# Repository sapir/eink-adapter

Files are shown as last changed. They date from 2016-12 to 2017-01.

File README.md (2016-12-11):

# E-Ink adapter board and driver code

See https://hackaday.io/project/7443-e-ink-display-adapter.

### Previous work and licensing

This is heavily based on previous work:
 * PetteriAimonen [explanations and PCB](http://essentialscrap.com/eink/index.html) (unknown license) and [driver code](https://github.com/PetteriAimonen/ED060SC4_driver) (public domain license)
 * Sprite_tm [explanations and PCB](http://spritesmods.com/?art=einkdisplay) (CC-BY-SA license) and [driver code](http://git.spritesserver.nl/espeink.git/) [(here's a github fork)](https://github.com/take-i/espeink) (beer-ware license)
 * zephray [NekoCal project](https://github.com/nbzwt/NekoCal), in particular the driver code (MIT license)

Additionally, the driver code uses the [esp-open-rtos ESP8266 SDK](https://github.com/Superhouse/esp-open-rtos.git) (various licenses).

As far as I'm concerned, I'd license this repository under the MIT license, but
the PCB may be under CC-BY-SA, and there may be other restrictions if you use
the esp-open-rtos SDK.

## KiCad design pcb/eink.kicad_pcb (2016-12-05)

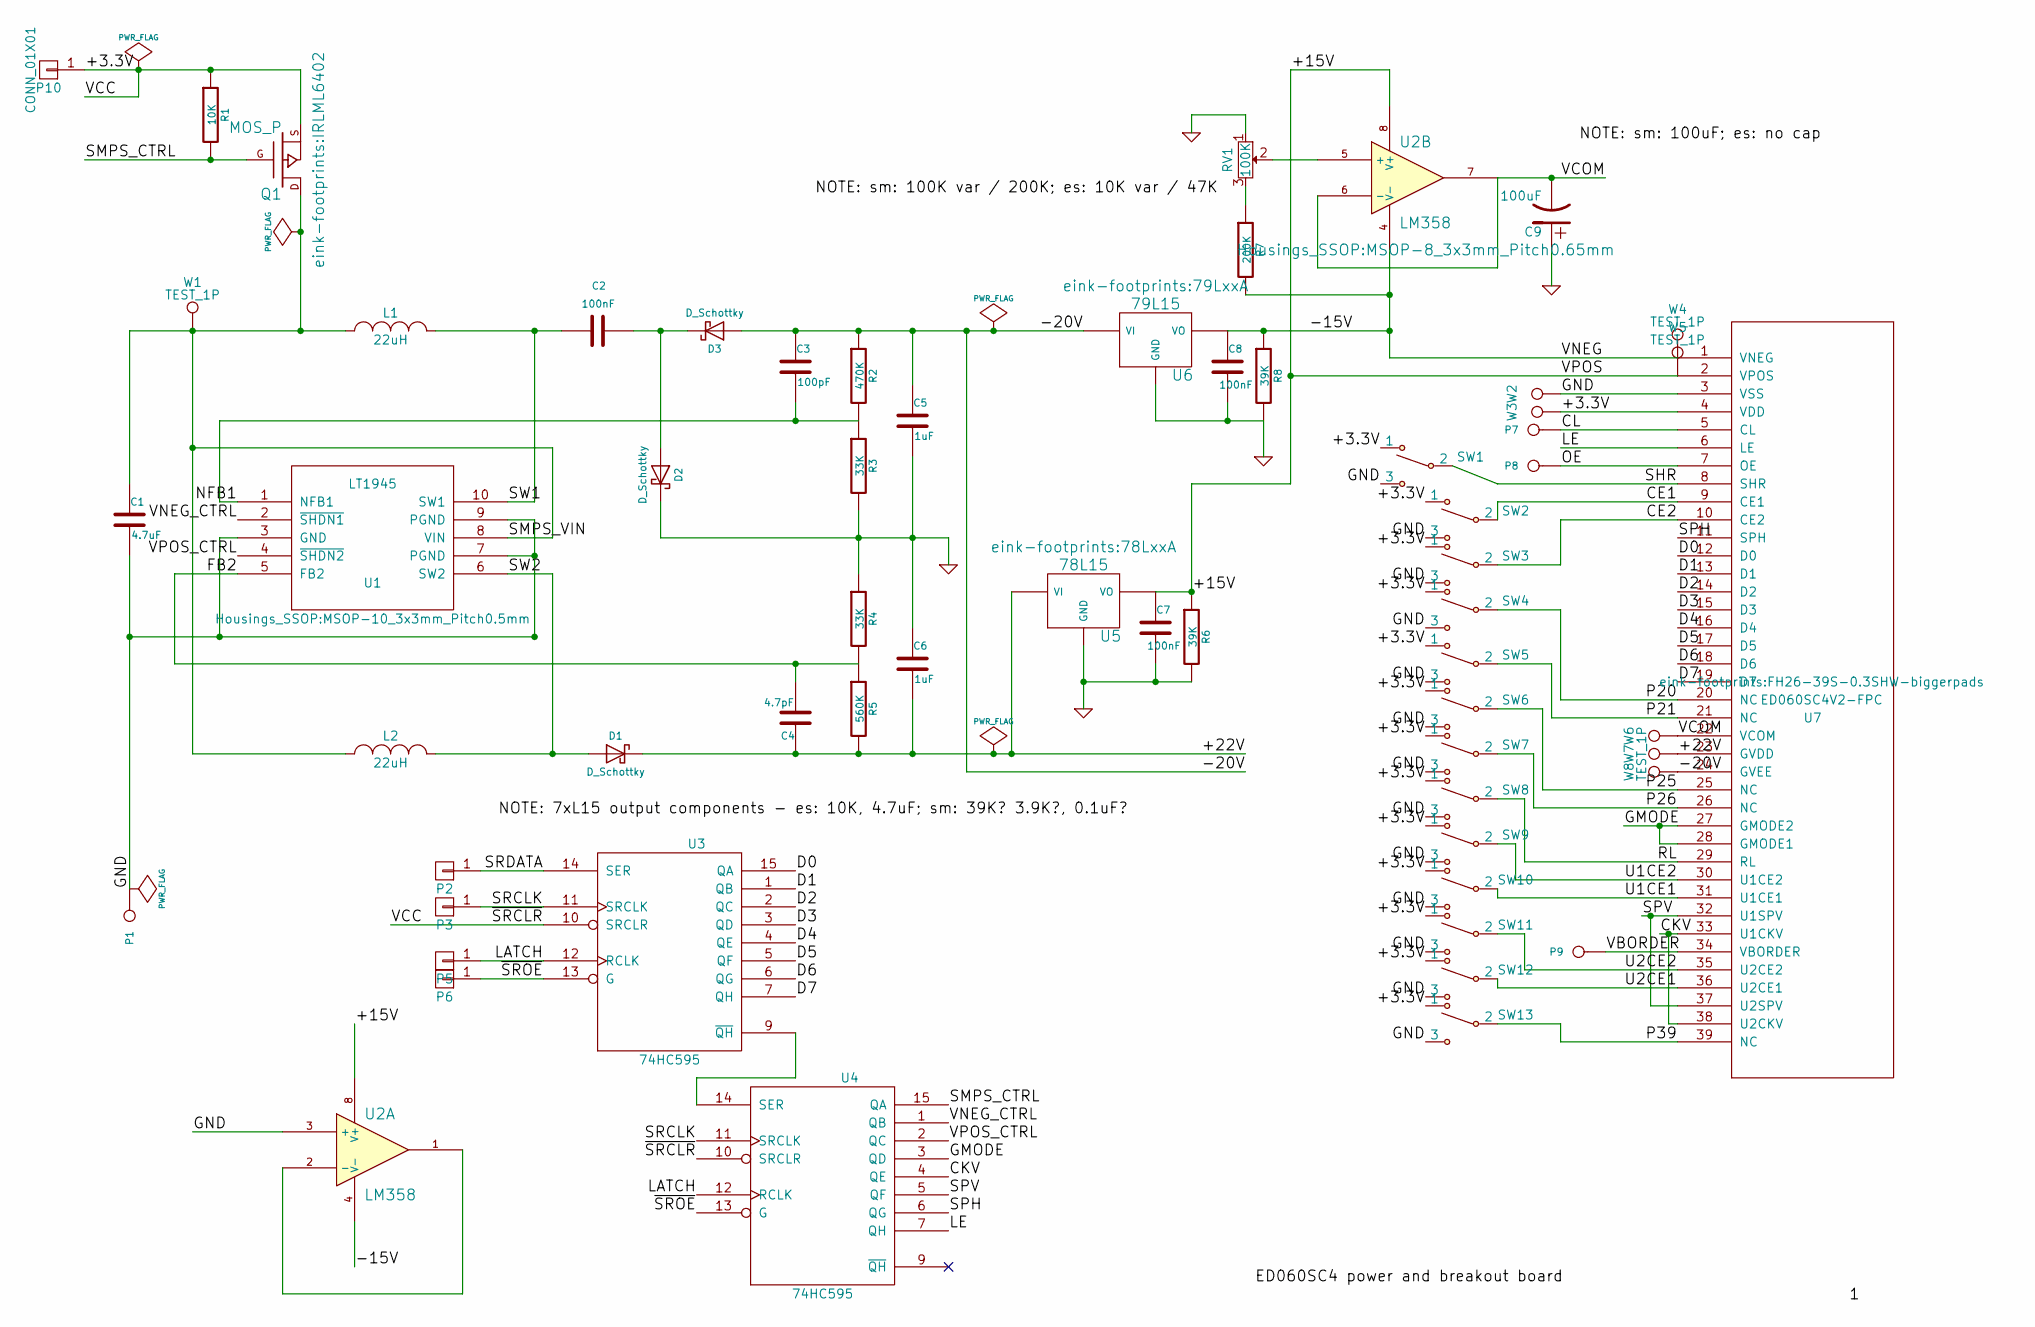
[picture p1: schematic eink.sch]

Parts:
C1: 4.7uF; C_0805_HandSoldering
C2, C7, C8: 100nF; C_0805_HandSoldering
C3: 100pF; C_0805_HandSoldering
C4: 4.7pF; C_0805_HandSoldering
C5, C6: 1uF; C_0805_HandSoldering
C9: 100uF; C_Radial_D5_L6_P2.5
D1, D2, D3: D_Schottky; SMB-SMC_Universal_Handsoldering
L1, L2: 22uH; SELF-WE-TPC_M
P1, P7, P8, P9: CONN_1; Pin_Header_Straight_1x01
P2, P3, P5, P6, P10: CONN_01X01; Pin_Header_Straight_1x01
Q1: MOS_P; IRLML6402
R1: 10K; R_0805_HandSoldering
R2: 470K; R_0805_HandSoldering
R3, R4: 33K; R_0805_HandSoldering
R5: 560K; R_0805_HandSoldering
R6, R8: 39K; R_0805_HandSoldering
R7: 200K; R_0805_HandSoldering
RV1: 100K; Bourns_3314G-1-biggerpads
SW1, SW2, SW3, SW4, SW5, SW6, SW7, SW8, SW9, SW10, SW11, SW12, SW13: SW_SPDT_Small; Pin_Header_Straight_1x03
U1: LT1945; MSOP-10_3x3mm_Pitch0.5mm
U2: LM358; MSOP-8_3x3mm_Pitch0.65mm
U3, U4: 74HC595; DIP-16_W7.62mm_LongPads
U5: 78L15; 78LxxA
U6: 79L15; 79LxxA
U7: ED060SC4V2-FPC; FH26-39S-0.3SHW-biggerpads
W1, W2, W3, W4, W5, W6, W7, W8: TEST_1P; Measurement_Point_Round-TH_Big

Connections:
/+15V: C7.1, R6.1, U2.8 (V+), U5.VO, U7.2 (VPOS), W5.1
/+22V: C4.1, C6.2, D1.1 (K), R5.2, U5.VI, U7.23 (GVDD), W7.1
/-15V: C8.1, R7.2, R8.1, U2.4 (V-), U6.VO, U7.1 (VNEG), W4.1
/-20V: C3.1, C5.1, D3.2 (A), R2.1, U6.VI, U7.24 (GVEE), W8.1
/CE1: SW2.2, U7.9 (CE1)
/CE2: SW3.2, U7.10 (CE2)
/CKV: U4.4 (QE), U7.33 (U1CKV), U7.38 (U2CKV)
/CL: P7.1, U7.5 (CL)
/D0: U3.15 (QA), U7.12 (D0)
/D1: U3.1 (QB), U7.13 (D1)
/D2: U3.2 (QC), U7.14 (D2)
/D3: U3.3 (QD), U7.15 (D3)
/D4: U3.4 (QE), U7.16 (D4)
/D5: U3.5 (QF), U7.17 (D5)
/D6: U3.6 (QG), U7.18 (D6)
/D7: U3.7 (QH), U7.19 (D7)
/FB2: C4.2, R4.2, R5.1, U1.5 (FB2)
/GMODE: U4.3 (QD), U7.27 (GMODE2), U7.28 (GMODE1)
/LATCH: P5.1, U3.12 (RCLK), U4.12 (RCLK)
/LE: U4.7 (QH), U7.6 (LE)
/NFB1: C3.2, R2.2, R3.1, U1.1 (NFB1)
/OE: P8.1, U7.7 (OE)
/P20: SW4.2, U7.20 (NC)
/P21: SW5.2, U7.21 (NC)
/P25: SW6.2, U7.25 (NC)
/P26: SW7.2, U7.26 (NC)
/P39: SW13.2, U7.39 (NC)
/RL: SW8.2, U7.29 (RL)
/SHR: SW1.2, U7.8 (SHR)
/SMPS_CTRL: Q1.G, R1.2, U4.15 (QA)
/SMPS_VIN: C1.1, L1.1, L2.1, Q1.D, U1.8 (VIN), W1.1
/SPH: U4.6 (QG), U7.11 (SPH)
/SPV: U4.5 (QF), U7.32 (U1SPV), U7.37 (U2SPV)
/SRCLK: P3.1, U3.11 (SRCLK), U4.11 (SRCLK)
/SRDATA: P2.1, U3.14 (SER)
/SW1: C2.1, L1.2, U1.10 (SW1)
/SW2: D1.2 (A), L2.2, U1.6 (SW2)
/U1CE1: SW10.2, U7.31 (U1CE1)
/U1CE2: SW9.2, U7.30 (U1CE2)
/U2CE1: SW12.2, U7.36 (U2CE1)
/U2CE2: SW11.2, U7.35 (U2CE2)
/VBORDER: P9.1, U7.34 (VBORDER)
/VCOM: C9.2, U2.6 (-), U2.7, U7.22 (VCOM), W6.1
/VNEG_CTRL: U1.2 (~SHDN1~), U4.1 (QB)
/VPOS_CTRL: U1.4 (~SHDN2~), U4.2 (QC)
/~SROE~: P6.1, U3.13 (G), U4.13 (G)
GND: C1.2, C5.2, C6.1, C7.2, C8.2, C9.1, D2.1 (K), P1.1, R3.2, R4.1, R6.2, R8.2, RV1.1, SW1.3, SW2.3, SW3.3, SW4.3, SW5.3, SW6.3, SW7.3, SW8.3, SW9.3, SW10.3, SW11.3, SW12.3, SW13.3, U1.3 (GND), U1.7 (PGND), U1.9 (PGND), U2.3 (+), U3.8 (GND), U4.8 (GND), U5.GND, U6.GND, U7.3 (VSS), W2.1
unnamed: C2.2, D2.2 (A), D3.1 (K)
unnamed: R7.1, RV1.3
unnamed: RV1.2, U2.5 (+)
unnamed: U2.1, U2.2 (-)
unnamed: U3.9 (~QH), U4.14 (SER)
VCC: P10.1, Q1.S, R1.1, SW1.1, SW2.1, SW3.1, SW4.1, SW5.1, SW6.1, SW7.1, SW8.1, SW9.1, SW10.1, SW11.1, SW12.1, SW13.1, U3.10 (SRCLR), U3.16 (VCC), U4.10 (SRCLR), U4.16 (VCC), U7.4 (VDD), W3.1

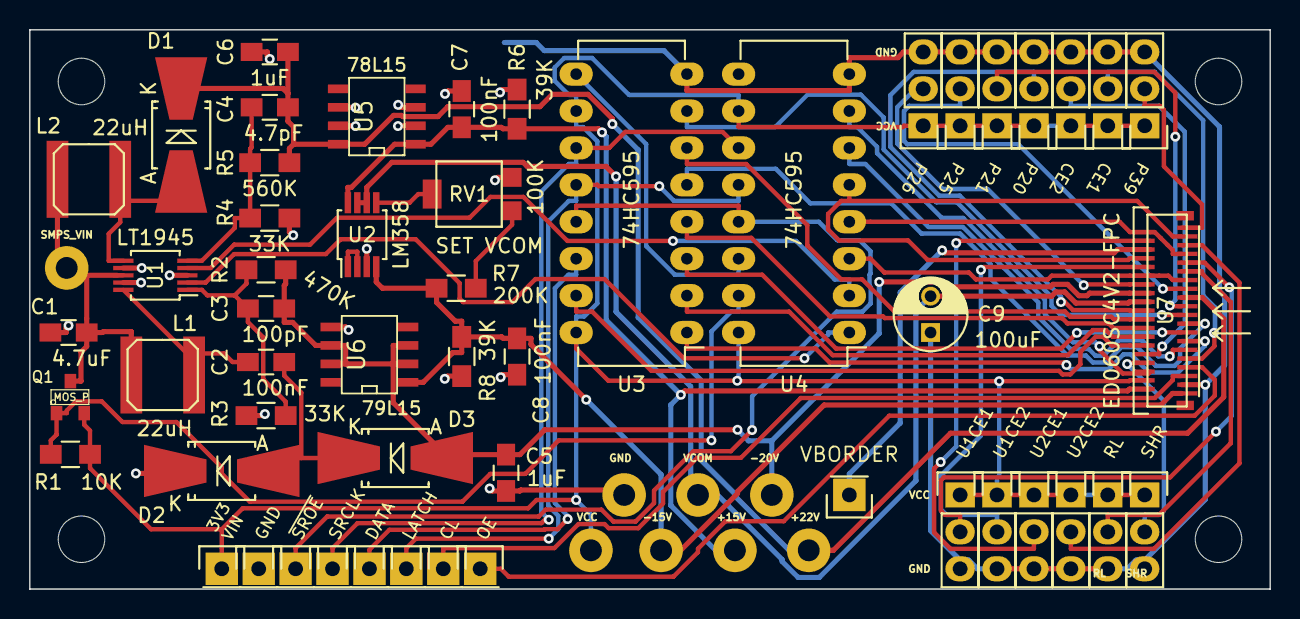
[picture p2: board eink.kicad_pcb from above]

Board: 2 copper layers, 85.3 x 38.5 mm, 65 parts (0 on the bottom side), 53 nets.

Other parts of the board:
MNT1, MNT2, MNT3, MNT4: MountingHole_3.2mm_M3

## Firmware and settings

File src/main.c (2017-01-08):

#include "espressif/esp_common.h"
#include "espressif/esp_wifi.h"
#include "espressif/esp_sta.h"
#include "espressif/user_interface.h"
#include <stdarg.h>
#include <string.h>
#include <lwip/sockets.h>
#include "esp/uart.h"
#include "FreeRTOS.h"
#include "task.h"
#include "eink.h"
#include "missing_api.h"
#include "skall.h"
#include "private_ssid_config.h"


#define LISTEN_PORT 3124


#define MY_UART 0


// a full frame buffer is 60KB, but we don't have that much available RAM on
// the ESP8266, so we get it in chunks
#define SCREEN_BITMAP_WIDTH 800
#define SCREEN_BITMAP_HEIGHT 600
#define SCREEN_BITMAP_X_OFS 0
#define SCREEN_BITMAP_Y_OFS 0
#define CHUNK_WIDTH 205
#define CHUNK_HEIGHT 205
#define CHUNK_OVERLAP 5

static uint8_t old_chunk[CHUNK_HEIGHT][CHUNK_WIDTH / PIXELS_PER_BYTE];
static uint8_t new_chunk[CHUNK_HEIGHT][CHUNK_WIDTH / PIXELS_PER_BYTE];


struct chunk_params {
    int x;
    int y;
    int byte_w;
};

bool get_rows_from_chunks(void *arg, int y, int x0, int x1, uint8_t *old_row,
    uint8_t *new_row)
{
    struct chunk_params *cp = arg;
    memcpy(old_row, old_chunk[y - cp->y], cp->byte_w);
    memcpy(new_row, new_chunk[y - cp->y], cp->byte_w);
    return true;
}


void handle_conn(int client_sock)
{
    printf("powering on...\n");
    eink_power_on();
    printf("here we go!\n");

    for (int y = 0; y < SCREEN_BITMAP_HEIGHT; y += CHUNK_HEIGHT - CHUNK_OVERLAP) {
        for (int x = 0; x < SCREEN_BITMAP_WIDTH; x += CHUNK_WIDTH - CHUNK_OVERLAP) {
            int w = SCREEN_BITMAP_WIDTH - x;
            if (w > CHUNK_WIDTH) w = CHUNK_WIDTH;

            int h = SCREEN_BITMAP_HEIGHT - y;
            if (h > CHUNK_HEIGHT) h = CHUNK_HEIGHT;

            int byte_w = (w+7)/8;

            if (!(sendall(client_sock, (void*)&x, sizeof(x))
                && sendall(client_sock, (void*)&y, sizeof(y))
                && sendall(client_sock, (void*)&w, sizeof(w))
                && sendall(client_sock, (void*)&h, sizeof(h))))
                continue;

            bool err = false;

            for (int row_y = 0; row_y < h; ++row_y) {
                if (!recvall(client_sock, old_chunk[row_y], byte_w)) {
                    err = true;
                    break;
                }
            }
            if (err)
                continue;

            for (int row_y = 0; row_y < h; ++row_y) {
                if (!recvall(client_sock, new_chunk[row_y], byte_w)) {
                    err = true;
                    break;
                }
            }
            if (err)
                continue;

            struct chunk_params cp = {
                .x = SCREEN_BITMAP_X_OFS + x,
                .y = SCREEN_BITMAP_Y_OFS + y,
                .byte_w = byte_w,
            };

            eink_update(get_rows_from_chunks, &cp,
                SCREEN_BITMAP_X_OFS + x,
                SCREEN_BITMAP_Y_OFS + y,
                SCREEN_BITMAP_X_OFS + x + w,
                SCREEN_BITMAP_Y_OFS + y + h);
        }
    }

    printf("powering off\n");
    eink_power_off();

    lwip_close(client_sock);
}

static bool connect_to_wifi(struct ip_info *info_ptr)
{
    printf("connecting to %s...\n", WIFI_SSID);

    struct sdk_station_config sta_config;
    bzero(&sta_config, sizeof(struct sdk_station_config));
    strcpy((char*)sta_config.ssid, WIFI_SSID);
    strcpy((char*)sta_config.password, WIFI_PASS);
    if (!sdk_wifi_station_set_config_current(&sta_config)) {
        printf("failed setting config\n");
        return false;
    }

    if (!sdk_wifi_station_connect()) {
        printf("failed connecting\n");
        return false;
    }

    printf("connected, starting DHCP\n");
    if (!sdk_wifi_station_dhcpc_start()) {
        printf("failed starting DHCP\n");
        return false;
    }

    printf("waiting for IP...\n");

    sdk_wifi_get_ip_info(STATION_IF, info_ptr);
    while (info_ptr->ip.addr == 0) {
        vTaskDelay(1000 / portTICK_PERIOD_MS);
        sdk_wifi_get_ip_info(STATION_IF, info_ptr);
    }

    printf("got %08x\n", info_ptr->ip.addr);
    return true;
}

void main_thread(void *arg)
{
    struct ip_info ip_config;
    while (!connect_to_wifi(&ip_config)) {
        printf("couldn't connect!\n");
    }

    int listen_sock = lwip_socket(AF_INET, SOCK_STREAM, 0);

    struct sockaddr_in listen_addr = {
        .sin_family = AF_INET,
        .sin_len = sizeof(struct sockaddr_in),
        .sin_addr = { .s_addr = htonl(INADDR_ANY) },
        .sin_port = htons(LISTEN_PORT)
    };

    lwip_bind(listen_sock, (struct sockaddr*)&listen_addr, sizeof(listen_addr));
    lwip_listen(listen_sock, 5);

    printf("clearing screen...\n");
    eink_power_on();
    eink_refresh(WHITE);
    eink_power_off();

    printf("listening...\n");

    for (;;) {
        struct sockaddr_in client_addr;
        socklen_t client_addrlen = sizeof(client_addr);
        int client_sock = lwip_accept(listen_sock,
            (struct sockaddr*)&client_addr, &client_addrlen);
        if (client_sock < 0) {
            printf("accept error %d\n", client_sock);
            break;
        }

        ip_addr_t addr = (ip_addr_t){ client_addr.sin_addr.s_addr };
        u16_t port = client_addr.sin_port;

        printf("got connection from " IPSTR ":%u\n",
             ip4_addr1(&addr), ip4_addr2(&addr),
             ip4_addr3(&addr), ip4_addr4(&addr),
             ntohs(port));

        handle_conn(client_sock);
    }

    lwip_close(listen_sock);

    vTaskDelete(NULL);
}


void user_init(void)
{
    sdk_wifi_set_opmode_current(STATION_MODE);

    uart_set_baud(MY_UART, 115200);
    printf("serial OK\n");

    if (!eink_setup()) {
        printf("eink setup fail\n");
        return;
    }

    printf("hw setup ok\n");

    int err = xTaskCreate(main_thread, "listen", 512, NULL, 1, NULL);
    if (pdPASS != err) {
        printf("error creating main thread: %d\n", err);
    }
}

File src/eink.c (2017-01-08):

#include "espressif/esp_common.h"
#include "espressif/esp_misc.h"
#include <string.h>
#include "esp/gpio.h"
#include "esp/spi.h"
#include "esp/interrupts.h"
#include "wemos_d1_mini.h"
#include "eink.h"
#include "waveform.h"


// SPI used for shift register
#define SR_SPI 1


// pins not included in shift registers:
#define PIN_SR_N_OE     PIN_D4      // shift register not-output-enable
#define PIN_CL          PIN_D2      // horizontal clock
// PIN_D1 conflicts with SPI-?
#define PIN_OE          PIN_D3      // display output enable
// SPI pins:
//      SRCLK           PIN_D5      // GPIO14
//      DATA            PIN_D7      // GPIO13
//      LATCH           PIN_D8      // GPIO15


// control bits: (low bits belong to shift register, top bits use extra pins)
#define BIT_SMPS        (1<<0)      // SMPS enable, active low
#define BIT_VNEG        (1<<1)      // -20V/-15V enable, active high
#define BIT_VPOS        (1<<2)      // +22V/+15V enable, active high
#define BIT_GMODE       (1<<3)      // GMODE, actually a 2-bit value but we
                                        // tied the 2 bits. 00 is off, 11 is on
#define BIT_CKV         (1<<4)      // vertical clock
#define BIT_SPV         (1<<5)      // start pulse vertical, active low
#define BIT_SPH         (1<<6)      // start pulse horizontal, active low
#define BIT_LE          (1<<7)      // source (horiz.) driver latch enable
#define BIT_CL          (1<<8)      // horizontal clock
#define BIT_OE          (1<<9)      // source (horiz.) driver output enable
                                        // (active high + CKV must be high?)
#define SR_BITS_MASK    0x00ff
#define EXTRA_BITS_MASK 0xff00

static uint16_t eink_ctl;
static uint8_t eink_data_byte;


// pixel values in a byte
#define PVS_PER_IO_BYTE 4

#define QUAD_PIXEL_VALUE(val) \
    ((val) | ((val)<<2) | ((val)<<4) | ((val)<<6))


// delay used for vscan_write when writing clear rows
#define CLEAR_WRITE_TIME_NS     5000


static void delay_ms(uint32_t ms)
{
    for (int i = 0; i < ms; ++i) {
        sdk_os_delay_us(1000);
    }
}

static void delay_us(uint32_t us)
{
    delay_ms(us / 1000);
    sdk_os_delay_us(us % 1000);
}

// TODO: only good for 50ns+, and ignores function call time
static inline void delay_25ns_steps(int steps)
{
    // at 80MHz, each cycle is 12.5ns, so 2 cycles are 25ns (1 step).
    // TODO: this naively assumes that each instruction is 1 cycle.
    register int i;
    __asm__ __volatile__ (
            "nop\n"
            "addi  %0, %1, -1\n"
        "0:\n"
            "addi  %0, %0, -1\n"
            "bgez  %0, 0b\n"
        : "=r"(i) : "r"(steps));
}


static inline uint16_t make_sr_val(uint16_t ctl, uint8_t data_byte)
{
    uint16_t sr_ctl = (ctl & SR_BITS_MASK);
    return ((uint16_t)sr_ctl << 8) | (uint8_t)data_byte;
}

// updates shift register only, not extra control pins
static void update_sr(void)
{
    spi_transfer_16(SR_SPI, make_sr_val(eink_ctl, eink_data_byte));
}

// updates extra control pins
static void update_extra(void)
{
    gpio_write(PIN_CL, (eink_ctl & BIT_CL) ? 1 : 0);
    gpio_write(PIN_OE, (eink_ctl & BIT_OE) ? 1 : 0);
}

static void update_ctl(void)
{
    update_sr();
    update_extra();
}

static inline void low(uint16_t pins)
{
    eink_ctl &= ~pins;
    if (pins & SR_BITS_MASK)
        update_sr();
    if (pins & EXTRA_BITS_MASK)
        update_extra();
}

static inline void high(uint16_t pins)
{
    eink_ctl |= pins;
    if (pins & SR_BITS_MASK)
        update_sr();
    if (pins & EXTRA_BITS_MASK)
        update_extra();
}


void eink_power_on(void)
{
    // clear everything (turning SMPS on), clear VNEG & VPOS
    eink_ctl = 0;
    update_ctl();

    delay_us(100);
    high(BIT_VNEG);

    delay_us(1000);
    high(BIT_VPOS);

    delay_us(10);
    high(BIT_SPV|BIT_SPH);
}

void eink_power_off(void)
{
    // turn everything off except voltage stuff
    eink_ctl &= (BIT_SMPS|BIT_VPOS|BIT_VNEG);

    delay_ms(10);

    low(BIT_VPOS);
    delay_ms(10);
    low(BIT_VNEG);
    delay_ms(100);
    // turn SMPS off by setting this bit
    high(BIT_SMPS);
}


static void hclk(int n)
{
    for (int i = 0; i < n; ++i) {
        high(BIT_CL);
        low(BIT_CL);
    }
}


static void hscan_start(void)
{
    high(BIT_OE);
    low(BIT_SPH);
}

static void data_write(uint8_t b)
{
    // we often have runs of the same data byte
    if (b != eink_data_byte) {
        eink_data_byte = b;
        update_sr();
    }
    hclk(1);
}

static void hscan_stop(void)
{
    high(BIT_SPH);
    hclk(2);

    high(BIT_LE);
    hclk(2);
    low(BIT_LE);
    hclk(2);
}

static void hscan_solid_row(int pixel_val)
{
    data_write(QUAD_PIXEL_VALUE(pixel_val));
    hscan_start();
    hclk(SCREEN_WIDTH/PVS_PER_IO_BYTE);
    hscan_stop();
}


static void vclk(int n)
{
    for (int i = 0; i < n; ++i) {
        low(BIT_CKV);
        delay_25ns_steps(60*20);
        high(BIT_CKV);
        delay_25ns_steps(60*20);
    }
}

// delays in nanoseconds
static void vscan_write(uint32_t ckv_high_delay, uint32_t ckv_low_delay)
{
    uint32_t high_steps = (ckv_high_delay + 24) / 25;
    uint32_t low_steps = (ckv_low_delay + 24) / 25;

    // don't let interrupts affect timing
    uint32_t old_interrupts = _xt_disable_interrupts();

    high(BIT_OE|BIT_CKV);
    delay_25ns_steps(high_steps);
    low(BIT_CKV);
    delay_25ns_steps(low_steps);
    low(BIT_OE);

    _xt_restore_interrupts(old_interrupts);

    hclk(2);
}


static void vscan_start(void)
{
    high(BIT_GMODE);
    delay_us(1000);

    high(BIT_SPV);
    vclk(2);
    low(BIT_SPV);
    vclk(2);
    high(BIT_SPV);
    vclk(2);
}

static void vscan_stop(void)
{
    hscan_solid_row(PV_NEUTRAL);
    vscan_write(CLEAR_WRITE_TIME_NS, CLEAR_WRITE_TIME_NS);

    delay_us(1);
    low(BIT_CKV|BIT_OE);
    delay_us(3000);
    high(BIT_CKV);
    delay_us(430);
    low(BIT_CKV);
    delay_us(1);
    low(BIT_GMODE);
    delay_us(1);
}


// do one stage of updating old row -> new_row
static void do_row_update_stage(int x0, int x1,
    uint8_t *old_row, uint8_t *new_row, int wf_stage)
{
    hscan_start();

    for (int x = 0; x < SCREEN_WIDTH; x += PVS_PER_IO_BYTE) {
        // build data byte from pixel values
        uint8_t val = 0;
        for (int i = 0; i < PVS_PER_IO_BYTE; ++i) {
            int xi = x + i;

            int pixel_val;

            if (x0 <= xi && xi < x1) {
                pixel_t old_pixel = get_row_pixel(old_row, xi - x0);
                pixel_t new_pixel = get_row_pixel(new_row, xi - x0);
                pixel_val = get_update_waveform_value(wf_stage,
                    old_pixel, new_pixel);
            } else {
                pixel_val = PV_NEUTRAL;
            }

            val <<= 2;
            val |= pixel_val;
        }

        data_write(val);
    }

    hscan_stop();
}
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

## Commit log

2015-09-29 Add kicad project, schematic and PCB files.
    [eink.kicad_pcb, eink.sch]
2015-09-29 Add text to back silkscreen.
    [eink.kicad_pcb]
2015-09-29 Fix up voltage annotation texts (on "drawing" layer).
    [eink.kicad_pcb]
2015-09-29 Export gerber files.
    [eink-B_Cu.gbl, eink-B_Mask.gbs, eink-B_SilkS.gbo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]
2015-09-30 Rotate (almost all) reference labels by 90 degrees.
    [eink.kicad_pcb]
2015-09-30 Update gerber files.
    [eink-B_Cu.gbl, eink-B_Mask.gbs, eink-B_SilkS.gbo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]
2015-10-05 Terminate the LM358's other op-amp.
    [eink.kicad_pcb, eink.sch]
2015-10-05 Partially rerun routing to fix some DRC violations (caused by manual routing :/ ).
    [eink.kicad_pcb]
2015-10-18 Fix FPC connector pinout and turn it around to face edge.
    [eink.kicad_pcb, eink.sch]
2016-04-10 New version of board for new version of KiCad :)
    [eink-B.Cu.gbl, eink-B.Mask.gbs, eink-B.SilkS.gbo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]
2016-10-19 Revision 2 of board with shift registers.
    [eink-B.Cu.gbl, eink-B.Mask.gbs, eink-B.Paste.gbp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]
2016-10-19 Add footprints library.
2016-11-29 Add more KiCAD files.
2016-12-05 Resave kicad files with a new (?) version, rescued trimpot part.
    [eink.kicad_pcb, eink.sch]
2016-12-05 Import WIP driver code.
2016-12-06 Update revision on schematic.
    [eink.sch]
2016-12-11 Add SPI pin definitions in a comment.
2016-12-11 Add comments about black/white voltages.
2016-12-11 Redo EPD output code based on NekoCal. Also, fixed delay functions.
    [eink.c]
2016-12-31 Skip using neutral vscan_writes instead of vclks or stopping vscan.
    [eink.c]
2016-12-31 Disable interrupts while writing to screen so they don't affect timing.
2017-01-08 Split missing API definitions to missing_api.h.
    [main.c]
